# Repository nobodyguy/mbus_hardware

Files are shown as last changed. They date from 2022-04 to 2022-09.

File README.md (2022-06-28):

# M-bus to USB board
* KiCAD 6.X required 
* includes ESD (USB+MBUS) and TVS (MBUS) protections
* includes AP3015 stepup from 5V -> 34V
* includes CH340E UART IC

## Software
Tested with https://github.com/ganehag/pyMeterBus library.

## 5V vs 3.3V note 
CH340E is 5V only IC without additional 3.3V regulator. Even its RX/TX pins are 5V.
Use PL2303GL instead when CH340E is not available and change MBUS logic to 3.3V (replace R6 and R10).

## Board overview
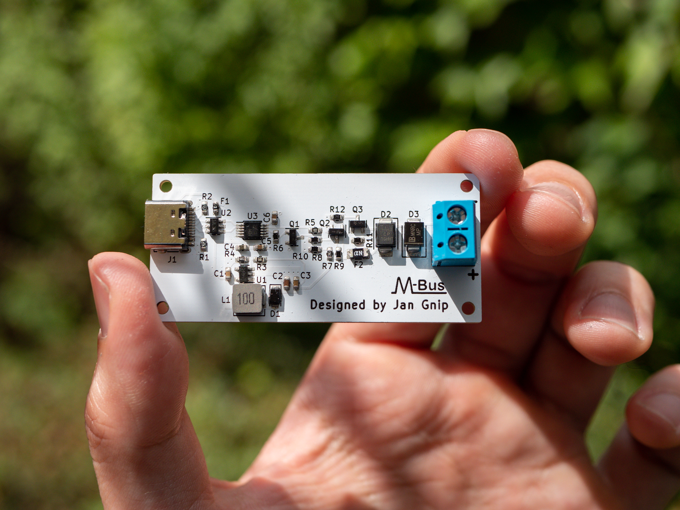
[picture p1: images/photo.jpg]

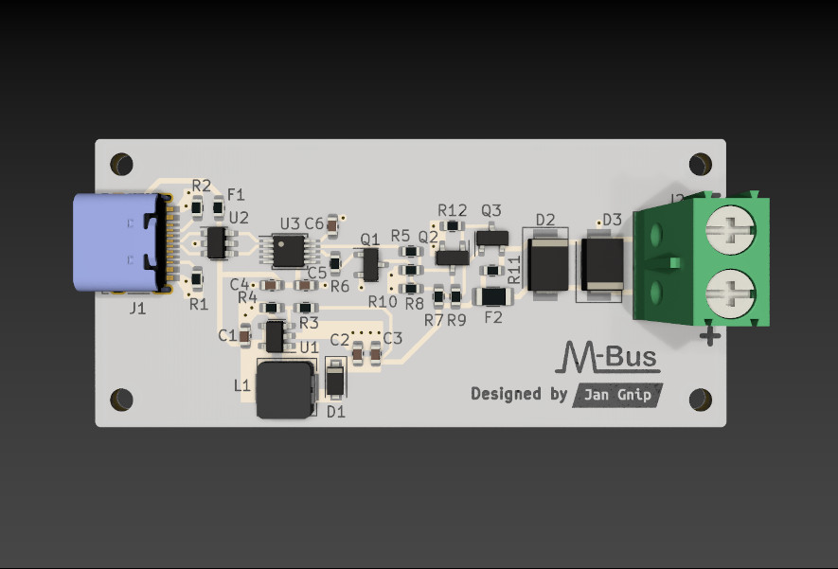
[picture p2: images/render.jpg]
Render

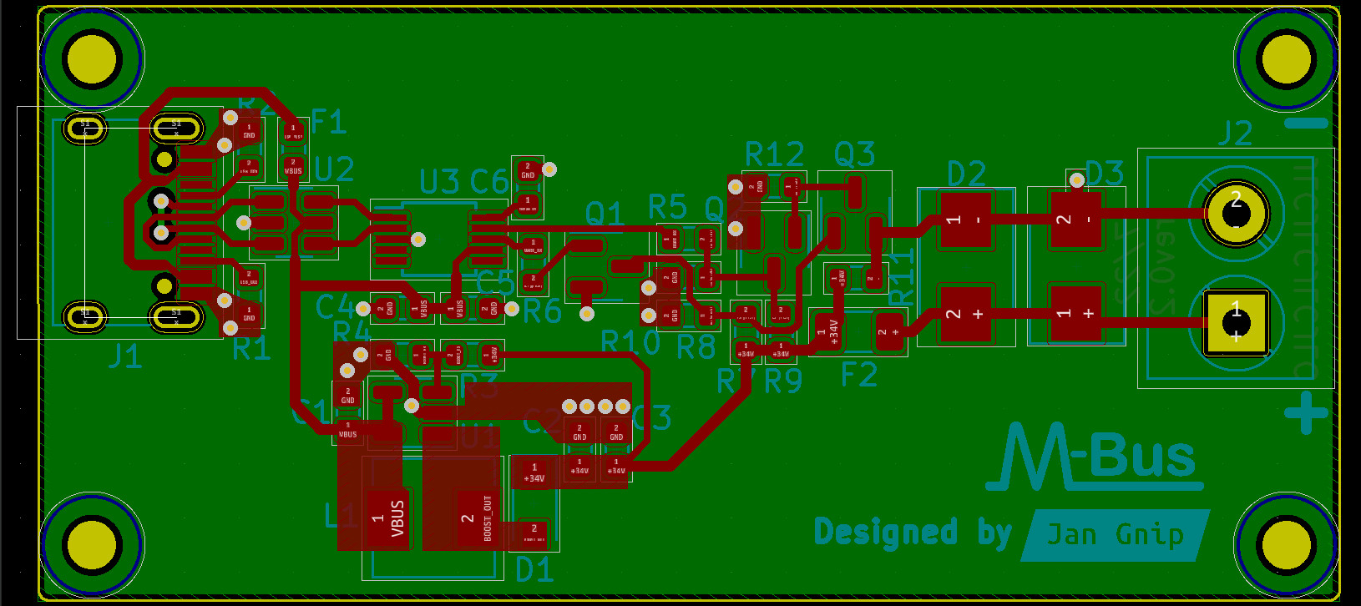
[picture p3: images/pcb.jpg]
PCB

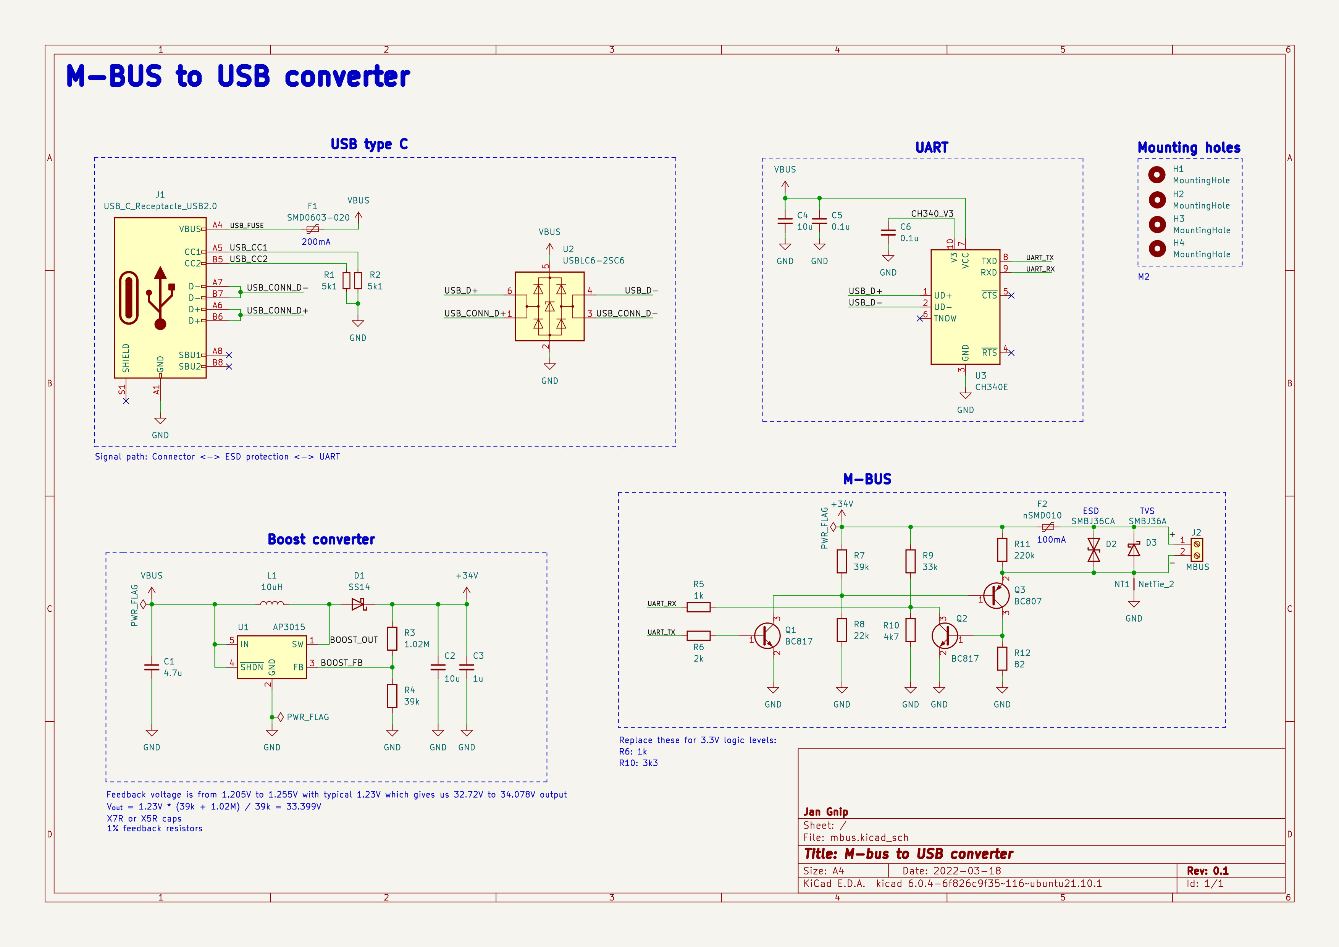
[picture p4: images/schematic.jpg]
Schematic


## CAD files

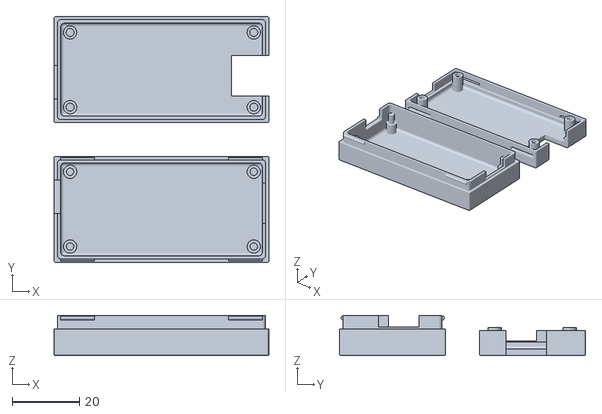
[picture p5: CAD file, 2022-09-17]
3D/box/mbus_box_snaps.stl
63.9 x 73.2 x 12.0

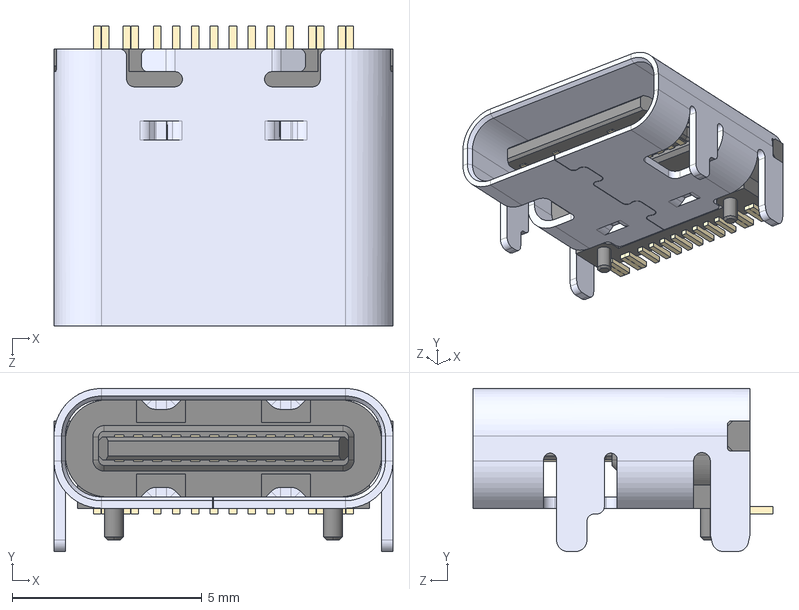
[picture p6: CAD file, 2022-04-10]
3D/TYPE-C-31-M-12--3DModel-STEP-56544.STEP
8.94 x 4.30 x 7.90 mm

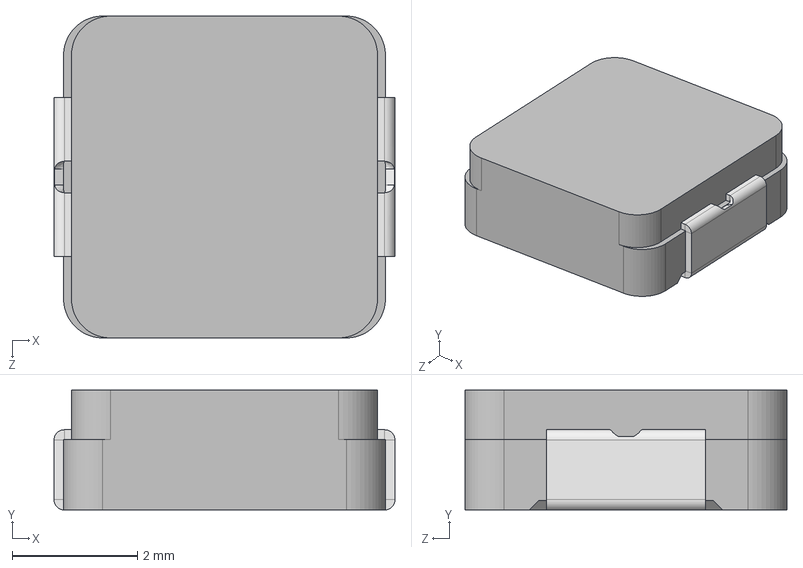
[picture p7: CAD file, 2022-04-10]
3D/IHLP2020BZ.STEP
5.45 x 1.92 x 5.15 mm

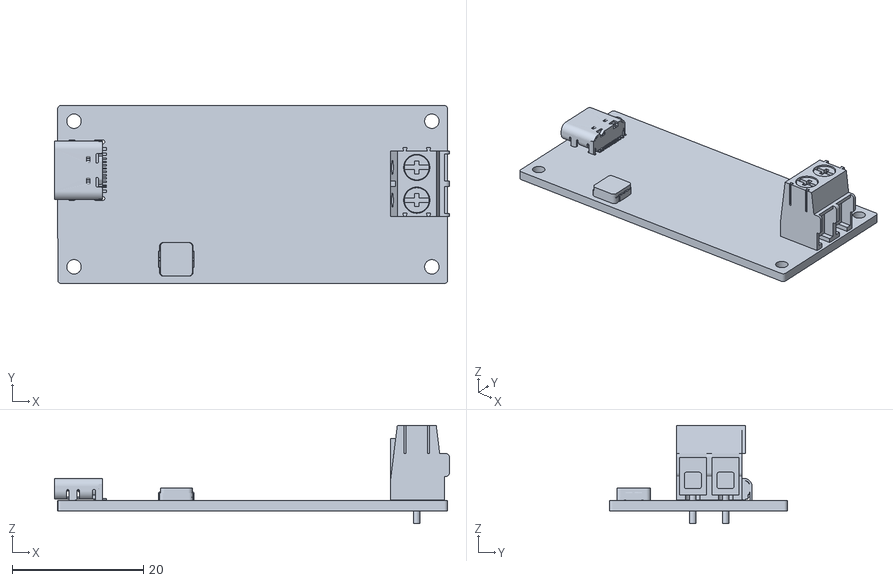
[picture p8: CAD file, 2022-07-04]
3D/box/mbus_pcb.stl
60.3 x 27.2 x 15.0

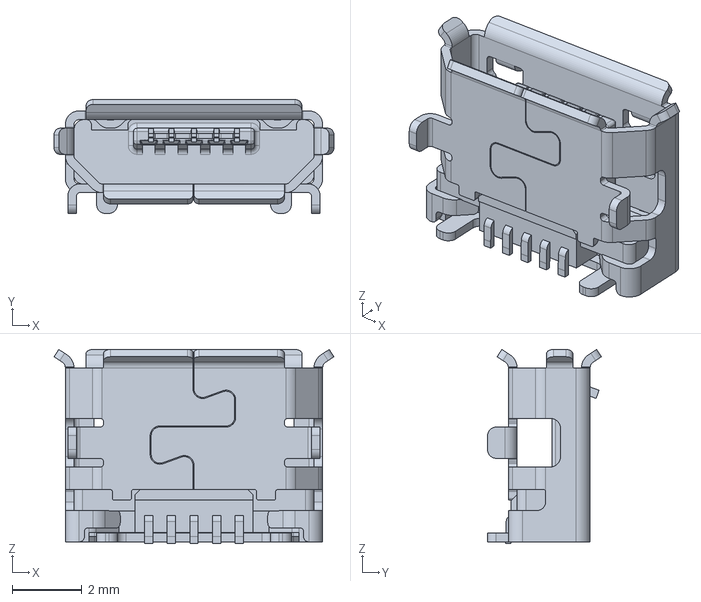
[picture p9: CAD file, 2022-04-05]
3D/10118194-0001LF.step
8.05 x 3.27 x 5.58 mm

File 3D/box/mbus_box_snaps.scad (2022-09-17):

//---------------------------------------------------------
// Yet Another Parameterized Projectbox generator
//
//  This is a box for MBUS
//
//  Version 0.2
//
// This design is parameterized based on the size of a PCB.
//---------------------------------------------------------
include <./library/YAPPgenerator_v14.scad>

// Note: length/lengte refers to X axis, 
//       width/breedte to Y, 
//       height/hoogte to Z

/*
      padding-back|<------pcb length --->|<padding-front
                            RIGHT
        0    X-as ---> 
        +----------------------------------------+   ---
        |                                        |    ^
        |                                        |   padding-right 
        |                                        |    v
        |    -5,y +----------------------+       |   ---              
 B    Y |         | 0,y              x,y |       |     ^              F
 A    - |         |                      |       |     |              R
 C    a |         |                      |       |     | pcb width    O
 K    s |         |                      |       |     |              N
        |         | 0,0              x,0 |       |     v              T
      ^ |   -5,0  +----------------------+       |   ---
      | |                                        |    padding-left
      0 +----------------------------------------+   ---
        0    X-as --->
                          LEFT
*/

printBaseShell      = true;
printLidShell       = true;

// Edit these parameters for your own board dimensions
wallThickness       = 2.0;
basePlaneThickness  = 2.0;
lidPlaneThickness   = 2.0;

baseWallHeight      = 10;
lidWallHeight       = 2;

// ridge where base and lid off box can overlap
// Make sure this isn't less than lidWallHeight
ridgeHeight         = 4;
ridgeSlack          = 0.2;
roundRadius         = 0.5;

// How much the PCB needs to be raised from the base
// to leave room for solderings and whatnot
standoffHeight      = 4.0;
pinDiameter         = 2.0;
pinHoleSlack        = 0.1;
standoffDiameter    = 4.0;

// Total height of box = basePlaneThickness + lidPlaneThickness 
//                     + baseWallHeight + lidWallHeight
pcbLength           = 59.54;
pcbWidth            = 27.18;
pcbThickness        = 1.6;
                            
// padding between pcb and inside wall
paddingFront        = 0.2;
paddingBack         = 0.2;
paddingRight        = 0.2;
paddingLeft         = 0.2;


//-- D E B U G -------------------
showSideBySide      = false;
hideLidWalls        = false;
onLidGap            = 0;
shiftLid            = 0;
colorLid            = "yellow";
hideBaseWalls       = false;
colorBase           = "white";
showPCB             = false;
showMarkers         = false;
inspectX            = 0;  // 0=none, >0 from front, <0 from back
inspectY            = 0;  // 0=none, >0 from left, <0 from right

labelsPlane = [];
//-- pcb_standoffs  -- origin is pcb[0,0,0]
// (0) = posx
// (1) = posy
// (2) = { yappBoth | yappLidOnly | yappBaseOnly }
// (3) = { yappHole, YappPin }
pcbStands = [
                [2.60,  2.55, yappBoth, yappPin],
                [pcbLength-2.32,  pcbWidth-2.40, yappBoth, yappPin],
                [pcbLength-2.32,  2.55, yappBoth, yappPin],
                [2.60, pcbWidth-2.40, yappBoth, yappPin],
             ];   

//-- Lid plane    -- origin is pcb[0,0,0]
// (0) = posx
// (1) = posy
// (2) = width
// (3) = length
// (4) = angle
// (5) = { yappRectangle | yappCircle }
// (6) = { yappCenter }
cutoutsLid =  [
                  [pcbLength, pcbWidth/2+1.8, 12, 18, 0, yappRectangle, yappCenter]
              ];

//-- base plane    -- origin is pcb[0,0,0]
// (0) = posx
// (1) = posy
// (2) = width
// (3) = length
// (4) = angle
// (5) = { yappRectangle | yappCircle }
// (6) = { yappCenter }
//cutoutsBase =   [
//[2.60,  2.53, 2, 0, 0,yappCircle, yappCenter]
//                    [10, 10, 20, 10, 45, yappRectangle]
//                  , [30, 10, 15, 10, 45, yappRectangle, yappCenter]
//                  , [20, pcbWidth-20, 15, 0, 0, yappCircle]
//                  , [pcbLength-15, 5, 10, 2, 0, yappCircle]
//                ];

//-- front plane  -- origin is pcb[0,0,0]
// (0) = posy
// (1) = posz
// (2) = width
// (3) = height
// (4) = angle
// (5) = { yappRectangle | yappCircle }
// (6) = { yappCenter }
cutoutsFront =  [
[pcbWidth/2+1.8, 11.5, 12, 11, 0, yappRectangle, yappCenter]
//                 [25, 3, 10, 10, 0, yappRectangle, yappCenter]  // center
                ];

//-- back plane  -- origin is pcb[0,0,0]
// (0) = posy
// (1) = posz
// (2) = width
// (3) = height
// (4) = angle
// (5) = { yappRectangle | yappCircle }
// (6) = { yappCenter }
cutoutsBack =   [
                    [12.3, -0.2, 10, 4.3, 0, yappRectangle]                // org
                  
                ];

//-- left plane   -- origin is pcb[0,0,0]
// (0) = posx
// (1) = posz
// (2) = width
// (3) = height
// (4) = angle
// (5) = { yappRectangle | yappCircle }
// (6) = { yappCenter }
//cutoutsLeft =   [
//                    [25, 0, 6, 20, 0, yappRectangle]                        // org
//                  , [pcbLength-35, 0, 20, 6, 0, yappRectangle, yappCenter] // center
//                  , [pcbLength/2, 10, 20, 6, 0, yappCircle]                // circle
//                ];

//-- right plane   -- origin is pcb[0,0,0]
// (0) = posx
// (1) = posz
// (2) = width
// (3) = height
// (4) = angle
// (5) = { yappRectangle | yappCircle }
// (6) = { yappCenter }
//cutoutsRight =  [
//                    [10, 0, 9, 5, 0, yappRectangle]                // org
//                  , [40, 0, 9, 5, 0, yappRectangle, yappCenter]    // center
//                  , [60, 0, 9, 5, 0, yappCircle]                   // circle
//                ];

//-- connectors -- origen = box[0,0,0]
// (0) = posx
// (1) = posy
// (2) = screwDiameter
// (3) = insertDiameter
// (4) = outsideDiameter
// (5) = { yappAllCorners }
//connectors   =  [
//                    [8, 8, 2.5, 3.8, 5, yappAllCorners]
//                  , [30, 8, 5, 5, 5]
//                ];

//-- base mounts -- origen = box[x0,y0]
// (0) = posx | posy
// (1) = screwDiameter
// (2) = width
// (3) = height
// (4..7) = yappLeft / yappRight / yappFront / yappBack (one or more)
// (5) = { yappCenter }
//baseMounts   = [
//                    [-5, 3.5, 10, 3, yappRight, yappCenter]
//                  , [0, 3.5, shellLength, 3, yappLeft, yappCenter]
//                  , [0, 3.5, 33, 3, yappLeft]
//                  , [shellLength, 3.5, 33, 3, yappLeft]
//                  , [shellLength/2, 3.5, 30, 3, yappLeft, yappCenter]
//                  , [10, 3.5, 15, 3, yappBack, yappFront]
//                  , [shellWidth-10, 3.5, 15, 3, yappBack, yappFront]
//               ];
               
//-- snap Joins -- origen = box[x0,y0]
// (0) = posx | posy
// (1) = width
// (2..5) = yappLeft / yappRight / yappFront / yappBack (one or more)
// (n) = { yappSymmetric }
/*
snapJoins   =     [
                    [2, 10, yappLeft, yappRight, yappSymmetric]
              //    [5, 10, yappLeft]
              //  , [shellLength-2, 10, yappLeft]
               //   , [30,  10, yappFront, yappBack]
              //  , [2.5, 3, 5, yappBack, yappFront, yappSymmetric]
                ];
*/               
//-- origin of labels is box [0,0,0]
// (0) = posx
// (1) = posy/z
// (2) = orientation
// (3) = plane {lid | base | left | right | front | back }
// (4) = font
// (5) = size
// (6) = "label text"
//labelsPlane =  [
//                    [10,  10,   0, "lid",   "Liberation Mono:style=bold", 7, "YAPP" ]
//                  , [100, 90, 180, "base",  "Liberation Mono:style=bold", 7, "Base" ]
//                  , [8,    8,   0, "left",  "Liberation Mono:style=bold", 7, "Left" ]
//                  , [10,   5,   0, "right", "Liberation Mono:style=bold", 7, "Right" ]
//                  , [40,  23,   0, "front", "Liberation Mono:style=bold", 7, "Front" ]
//                  , [5,    5,   0, "back",  "Liberation Mono:style=bold", 7, "Back" ]
//               ];
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

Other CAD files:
3D/box/mbus_box_without_snaps.stl

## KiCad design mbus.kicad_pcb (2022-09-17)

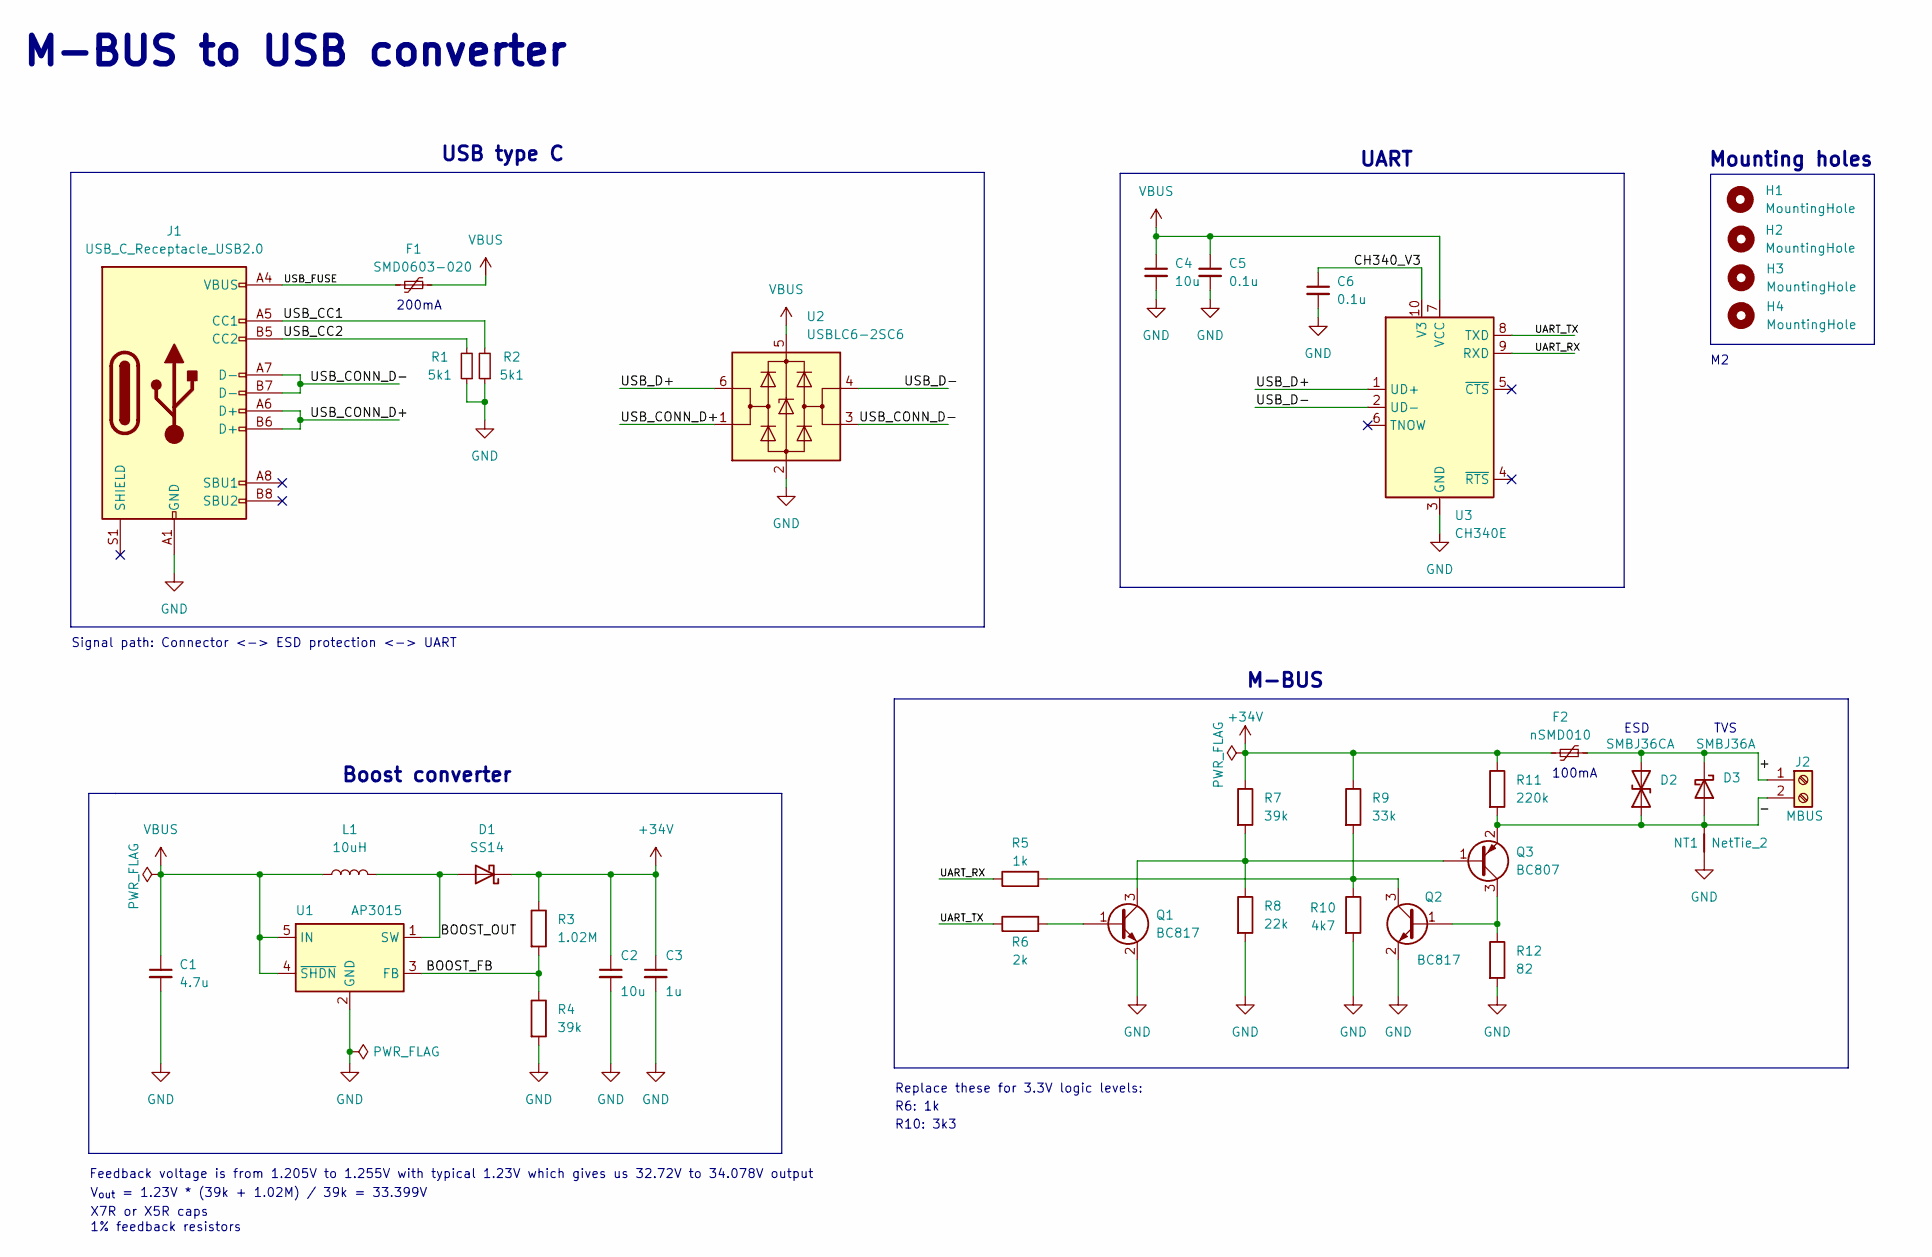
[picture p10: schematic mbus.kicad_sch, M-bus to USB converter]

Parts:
C1: 4.7u; C_0603_1608Metric; LCSC Part C1705
C2: 10u; C_0603_1608Metric; LCSC Part C2911377
C3: 1u; C_0603_1608Metric; LCSC Part C77386
C4: 10u; C_0603_1608Metric; LCSC Part C109455
C5, C6: 0.1u; C_0603_1608Metric; LCSC Part C14663
D1: SS14; D_SOD-123F; LCSC Part C190475
D2: SMBJ36CA; D_SMB; LCSC Part C83326
D3: SMBJ36A; D_SMB; LCSC Part C84731
F1: SMD0603-020; Fuse_0603_1608Metric; LCSC Part C2760255
F2: nSMD010; Fuse_1206_3216Metric; LCSC Part C70065
H1, H2, H3, H4: MountingHole; MountingHole_2.2mm_M2
J1: USB_C_Receptacle_USB2.0; USB_C_Receptacle_HRO_TYPE-C-31-M-12; LCSC Part C165948
J2: MBUS; TerminalBlock_Phoenix_PT-1,5-2-5.0-H_1x02_P5.00mm_Horizontal; LCSC Part C474881
L1: 10uH; L_Sunlord_MWSA0518_5.4x5.2mm; LCSC Part C408412
NT1: NetTie_2; NetTie-2_SMD_Pad0.5mm
Q1, Q2: BC817; SOT-23; LCSC Part C604682
Q3: BC807; SOT-23; LCSC Part C82369
R1, R2: 5k1; R_0603_1608Metric; LCSC Part C105580
R3: 1.02M; R_0603_1608Metric; LCSC Part C227665
R4, R7: 39k; R_0603_1608Metric; LCSC Part C118370
R5: 1k; R_0603_1608Metric; LCSC Part C966204
R6: 2k; R_0603_1608Metric; LCSC Part C445827
R8: 22k; R_0603_1608Metric; LCSC Part C441928
R9: 33k; R_0603_1608Metric; LCSC Part C441899
R10: 4k7; R_0603_1608Metric; LCSC Part C441894
R11: 220k; R_0603_1608Metric; LCSC Part C441934
R12: 82; R_0603_1608Metric; LCSC Part C445805
U1: AP3015; SOT-23-5; LCSC Part C151334
U2: USBLC6-2SC6; SOT-23-6; LCSC Part C2827654
U3: CH340E; MSOP-10_3x3mm_P0.5mm; LCSC Part C99652

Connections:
+34V: C2.1, C3.1, D1.1 (K), F2.1, R3.1, R7.1, R9.1, R11.1
/+: D2.2 (A2), D3.1 (K), F2.2, J2.1
/-: D2.1 (A1), D3.2 (A), J2.2, NT1.2, Q3.2 (E), R11.2
/BOOST_FB: R3.2, R4.1, U1.3 (FB)
/BOOST_OUT: D1.2 (A), L1.2, U1.1 (SW)
/CH340_V3: C6.1, U3.10 (V3)
/UART_RX: R5.1, U3.9 (RXD)
/UART_TX: R6.1, U3.8 (TXD)
/USB_CC1: J1.A5 (CC1), R2.2
/USB_CC2: J1.B5 (CC2), R1.2
/USB_CONN_D+: J1.A6 (D+), J1.B6 (D+), U2.1 (I/O1)
/USB_CONN_D-: J1.A7 (D-), J1.B7 (D-), U2.3 (I/O2)
/USB_D+: U2.6 (I/O1), U3.1 (UD+)
/USB_D-: U2.4 (I/O2), U3.2 (UD-)
/USB_FUSE: F1.1, J1.A4 (VBUS), J1.A9 (VBUS), J1.B4 (VBUS), J1.B9 (VBUS)
GND: C1.2, C2.2, C3.2, C4.2, C5.2, C6.2, J1.A1 (GND), J1.A12 (GND), J1.B1 (GND), J1.B12 (GND), NT1.1, Q1.2 (E), Q2.2 (E), R1.1, R2.1, R4.2, R8.2, R10.2, R12.2, U1.2 (GND), U2.2 (GND), U3.3 (GND)
unnamed: Q1.1 (B), R6.2
unnamed: Q1.3 (C), Q3.1 (B), R7.2, R8.1
unnamed: Q2.1 (B), Q3.3 (C), R12.1
unnamed: Q2.3 (C), R5.2, R9.2, R10.1
VBUS: C1.1, C4.1, C5.1, F1.2, L1.1, U1.4 (~SHDN), U1.5 (IN), U2.5 (VBUS), U3.7 (VCC)

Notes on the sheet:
R10: 3k3
V_{out} = 1.23V * (39k + 1.02M) / 39k = 33.399V
UART
Boost converter
100mA
TVS
Replace these for 3.3V logic levels:
USB type C
200mA
ESD
M-BUS
Mounting holes
Signal path: Connector <-> ESD protection <-> UART
X7R or X5R caps
Feedback voltage is from 1.205V to 1.255V with typical 1.23V which gives us 32.72V to 34.078V output
R6: 1k
M-BUS to USB converter
1% feedback resistors

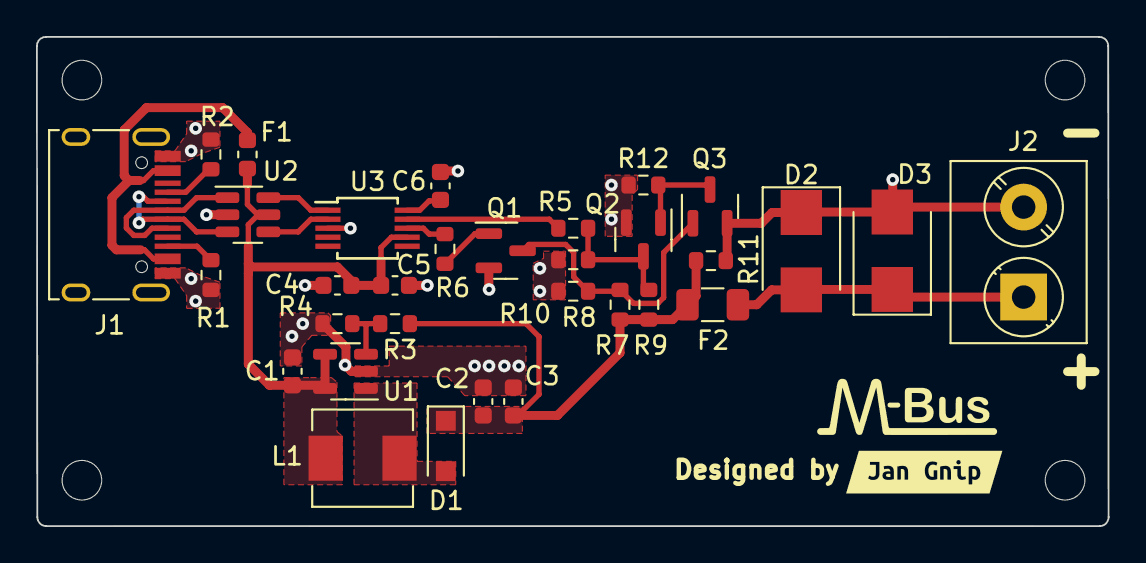
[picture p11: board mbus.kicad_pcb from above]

Board: 2 copper layers, 59.5 x 27.2 mm, 38 parts (0 on the bottom side), 21 nets.

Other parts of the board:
kibuzzard-62A19C5B: G***; kibuzzard-62A19C5B

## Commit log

2022-03-18 Finished USB
    [mbus.kicad_pcb, mbus.kicad_sch]
2022-03-19 mbus driving logic WIP
    [mbus.kicad_sch]
2022-03-21 Added boost converter, protection components for mbus
    [mbus.kicad_sch]
2022-03-23 Generated designators
    [mbus.kicad_sch]
2022-04-05 Replaced 500mA VBUS fuse with 200mA, changed MBUS circuit to work with 5V logic
    [mbus.kicad_sch]
2022-04-05 Added 5V/3.3V note to readme
2022-04-05 Added microUSB footprint with 3D model
    [10118194-0001LF.step, mbus.kicad_pcb]
2022-04-07 Added part numbers, schematic to readme and symbol for mbus power rail
    [mbus.kicad_sch]
2022-04-10 Replaced microUSB with type C, changed ESD protection IC
    [IHLP2020BZ.STEP, TYPE-C-31-M-12--3DModel-STEP-56544.STEP, mbus.kicad_pcb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]
2022-04-10 Fixed footprint library link, updated exported schematic
    [mbus.kicad_sch]
2022-04-16 PCB component placement WIP
    [mbus.kicad_pcb, mbus.kicad_sch]
2022-04-18 PCB placement done
    [mbus.kicad_pcb]
2022-04-18 Added mounting holes, board outline done
    [mbus.kicad_pcb, mbus.kicad_sch]
2022-04-19 PCB rev0.1 finished
    [mbus.kicad_pcb, mbus.kicad_sch]
2022-04-19 Added manufacturing exports
    [mbus-B_Cu.gbr, mbus-B_Mask.gbr, mbus-B_Paste.gbr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]
2022-04-19 Fixed LCSC part IDs
    [mbus.kicad_sch]
2022-04-20 Added CH340N symbol just in case, added part numbers for the rest of the passive components
    [mbus.kicad_pcb, mbus.kicad_sch]
2022-04-26 Added final PCB image and 3D render
2022-04-26 Updated manufacturing exports
    [mbus-B_Cu.gbr, mbus-B_Mask.gbr, mbus-B_Paste.gbr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]
2022-04-26 Fixed USB connector shield pins net to pass DRC
    [mbus.kicad_pcb]
2022-06-09 rev 0.2 - swapped RX/TX pins
    [mbus-B_Cu.gbr, mbus-B_Mask.gbr, mbus-B_Paste.gbr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]
2022-06-28 Added photo of working board
2022-07-04 Added 3D box model
    [mbus_box_snaps.scad, mbus_pcb.stl]
2022-07-04 Exported 3D box
    [mbus_box_snaps.scad, mbus_box_snaps.stl]
2022-09-17 Changes to enclosure, added TVS nettie
    [mbus.kicad_pcb, mbus.kicad_sch, mbus_box_snaps.scad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]
